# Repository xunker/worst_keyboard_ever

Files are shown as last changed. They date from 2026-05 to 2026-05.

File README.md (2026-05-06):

# Worst. Keyboard. Ever.

https://github.com/xunker/worst_keyboard_ever

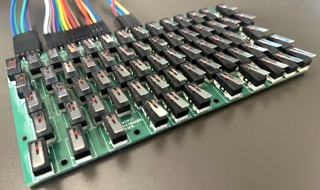
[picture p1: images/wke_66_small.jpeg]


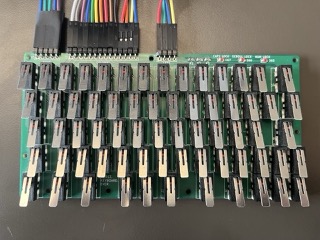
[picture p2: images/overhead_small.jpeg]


It's a mechanical keyboard made from limit switches[^1]. Sorry.

## Parts

Part                      | Quantity | Notes
--------------------------|----------|------
[PCB](kicad)              | 1        | Using more than one is not recommended
Omron D2F-FL              | 66       | [^2]
1N4148 Diode              | 66       | SOT-123 package recommended, but you can use LL34 (MiniMELF) if you like things that roll away while you're soldering them
2.54MM pin (male) headers | 23 pos   | Use whatever fits in the holes[^3]
0805 LED                  | 3        | Prefer the kind that light up; LEDs that don't light up are not good indicators
0805 330 ohm resistor     | 3        | You'll learn to solder SMD components and you'll _like it_

Your microcontroller is not listed. Use whatever you like. There's [QMK firmware](#firmware) for the Pi Pico if you want it.

## Matrix

| row/col | 0 | 1 | 2 | 3 | 4 | 5 | 6 | 7 | 8 | 9 | 10  | 11 | 12 | 13 |
|---|---|-----|-----|---|---|---|---|-----|-----|-----|-----|---|---|---|
| 0 | esc  | 1 | 2 | 3 | 4 | 5 | 6 | 7 | 8 | 9 | 0 | - | = | bksp  |
| 1 | tab  | q | w | e | r | t | y | u | i | o | p | [ | ] | \ |
| 2 | cap  | a | s | d | f | g | h | j | k | l | ; | ' | ent  | --- |
| 3 | shft | z | x | c | v | b | n | m | , | . | / | shft | up | fn |
| 4 | ctrl | win | alt |  --- | spc1 | spc2 | spc3 | --- | --- | alt | app | left | down | right |

## LEDs

The caps/num/scroll LEDs are _active-low_. That means the `common` pin should be connected to your microcontroller's VCC, and the LEDs are activated by pulling the approriate pin to ground.

If you're using a 3.3V MCU like the Pi Pico, do **NOT** connect `common` to a 5V source like VBUS or USB power. If you do that, you'll _fry_ your MCU you'll be sad.

## Firmware

There is QMK firmware available, targeting the Raspberry Pi Pico (RP2040). Find it in the [qmk_firmware](qmk_firmware/keyboards/wke_66) directory.

If you don't want to build it yourself, and you don't need to customize anything, a [prebuild .u2f file](./wke_wke_66_default.uf2) is also available.

# Useless Questions

## Why?

Because I needed **one** switch, but it was cheaper to buy a whole gross of them.

## The switches are too close together

I recommend installing smaller fingers on one or both hands.

## I've used worse keyboards than this!

1) "Worst. Keyboard. Ever." is a product/marketing name.
2) No you haven't.

## A Scroll Lock LED? Really?

Don't worry about it. No one in the history of the world has **ever** used Scroll Lock. No, not even _that one guy from the internet_, he's lying.

## Is there an ISO version?

Assuming drills exist, yes.

## It has no legends!

If you're asking for key legends, that means you want to use this as an _actual_ keyboard to type _real_ things. That's a crazy idea, you should stand up and slowly back away.

But, if you insist, [here are some suggestions](SERIOUSLY.md#no-legends).

## Your soldering is terrible!

Wrong, _MY_ soldering is AWESOME. My _cat's_ soldering is terrible.

Note: Cat hair seen in the [photos](images/) is __not included__.

# License

[CC BY-NC-SA 4.0](LICENSE)

[^1]: Variously called "limit switches", "lever switches", or "detect switches".

[^2]: Be honest, you're not going to use _real_ Omron switches, are you? You're going to use some knock-off, admit it.

[^3]: That's what she said.

I sure hope you enjoy soldering diodes!

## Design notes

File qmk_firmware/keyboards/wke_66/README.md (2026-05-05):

# Worst Keyboard Ever -- 66 key edition
## wke_66

Main project URL: https://github.com/xunker/worst_keyboard_ever

wke_66

* Keyboard Maintainer: [M Nielsen](https://github.com/xunker/worst_keyboard_ever)
* Hardware Supported: Pi Pico (RP2040)
* Hardware Availability: https://raspberrypi.org

## Building this firmware

(This assumes you've already cloned the QMK repo and configured your environment.)

First, clone the [parent repo](https://github.com/xunker/worst_keyboard_ever).

Then, symlink the `qmk_firmware/keyboards/wke_66` directory in to your main "qmk_firmware" directory:

```bash
ln -s qmk_firmware/keyboards/wke_66 ~/qmk_firmware/keyboards/wke_66
```

(You could also just copy the files to `~/qmk_firmware/keyboards/wke_66`, but where's the fun in that?)

> [!IMPORTANT]
>
> If you're using MacOS, you need to install a specific version of `gcc-arm-embedded`, the default version in Homebrew _is broken_.
>
> `brew install --cask gcc-arm-embedded`

Now, build the firmware:
```bash
# from ~/qmk_firmware
PATH=/Applications/ArmGNUToolchain/15.2.rel1/arm-none-eabi/bin:$PATH qmk compile -kb wke/wke_66 -km default

# you can also lint the firmware with `qmk lint -kb wke/wke_66 -km default`
```

This will make a `wke_wke_66_default.uf2`. Drag that file to your Pi Pico and you're off!

## Bootloader

To re-enter the Bootloader (like if you need to flash new firmware), you have 3 options:

* **Bootmagic reset**: Hold down the key at (0,0) in the matrix (usually the top left key or Escape) and plug in the keyboard
* **Physical button**: Hold down the "bootsel" button on the Pi Pico **while** plugging the board in to USB
* **Keycode**: While the keyboard is connected and running, hold down the `fn` key and press the "App"/"Menu" button

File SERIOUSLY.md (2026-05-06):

# Worst. Keyboard. Ever.

https://github.com/xunker/worst_keyboard_ever

# Serious answers

## Why?

These lever-style switches, even the cheap copies, have a really satisfying
action. So I found myself wondering what a keyboard made from these would feel
like.

I wanted to use larger SS-5GL/KW-11/KW-12 switches, but that made the board to
large and would cost too much to fab.

## Why is it "the worst"?

### No legends

There's no easy way to add legends.

Using masking tape or a label maker is the most obvious solution, but that's
more work than most people are prepared to do (after soldering 66 SMD diodes and
198 switch pins).

If I'd been more diligent in the PCB design, I would have made sure to have
silkscreens in the top-left corner of each unit, but I didn't know enough about
Kicad at the time (May 2022).

Here are some ideas for adding legends:
* Permanent Marker with an extra-fine tip, and a very steady hand
* Masking tape
* Label printer + scissors
* Laser marking
* 3D-printed or laser-cut "piano-key" cover

### Narrow key spacing

The key spacing is `2*(switch width)`, and that's too narrow for most people's
fingers.

I needed to keep the PCB under 100MM^2 in order to qualify for the cheap fab
options, and this was the best option.

### No "home row" bumps

Not that you'll be touch-typing on this, but even if you could there are no home
row bumps.

You could use a bit of glue to make a bump, I guess.

The best way would be to use D2F-L3/D2F-FL3 "simulated roller" switches in place
of "F" and "J", but I didn't think of that ahead of time.

### Fingers catch on levers

Your fingers will catch on the edge of the levers, and that really can't be
helped.

However, having the switches in the other orientation (levers pointing toward
the far-edge of the PCB) was **even worse**.

### Outboard MCU

When I make this PCB I had no idea what MCU I wanted to use. And even if I did,
that would have pushed the size past the $5 tier for PCB fabbing.

So I made the MCU connection completely outboard, via header connectors. It's
not a terrible thing to do, but I could have done better.

## Why it's not "the worst"

Despite the name, it does have some things going for it.

* It **is** a fully functional mechanical keyboard
* Small, very portable
* Fully compatible with QMK, ZMK, KMK, etc
* Great soldering practice

## Ideas for the future

### Use "simulated roller" switches

Use D2F-L3/D2F-FL3 "simulated roller" switches for "home row" bumps, and for
arrow keys. That would make it much easier to differntiate those keys.

### Align silkscreen legends better

Make sure the PCB legend silkscreens are aligned in the top-left corner, so they
are visible even when the switch is soldered in place.

### More switch placement options

Have more options for spacebar and arrow key locations.

Add options for ISO pipe and enter.

Add options for JIS pipe and backspace.

### RGB

Why not? To paraphrase Bill Hicks, "you're already within the Dark Lord's
domain."

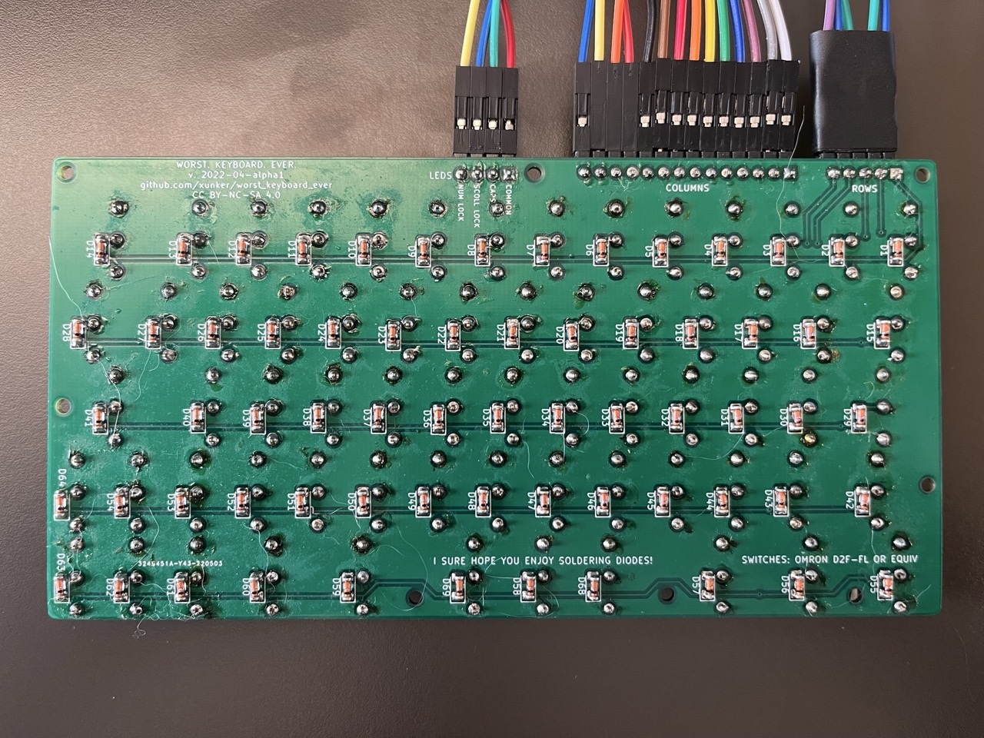
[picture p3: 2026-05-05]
images/underneath.jpeg

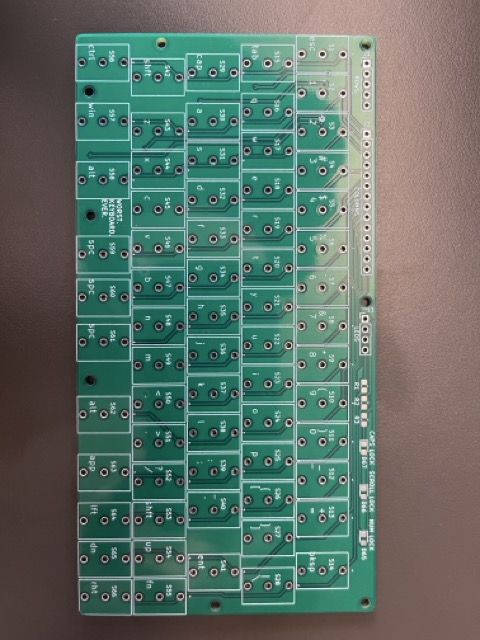
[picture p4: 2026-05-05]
images/pcb_front.jpeg

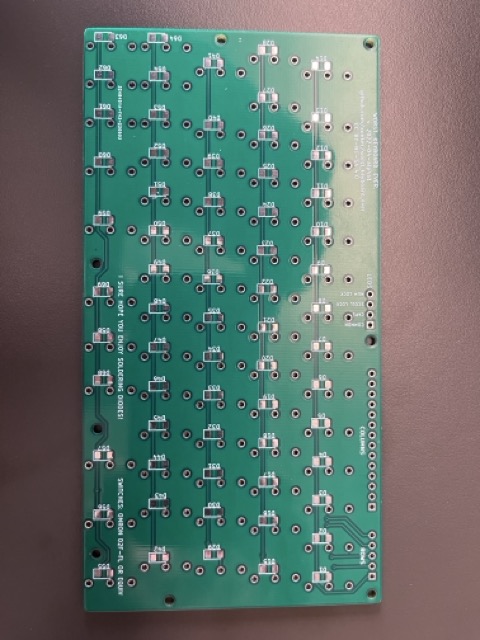
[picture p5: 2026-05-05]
images/pcb_not_front.jpeg

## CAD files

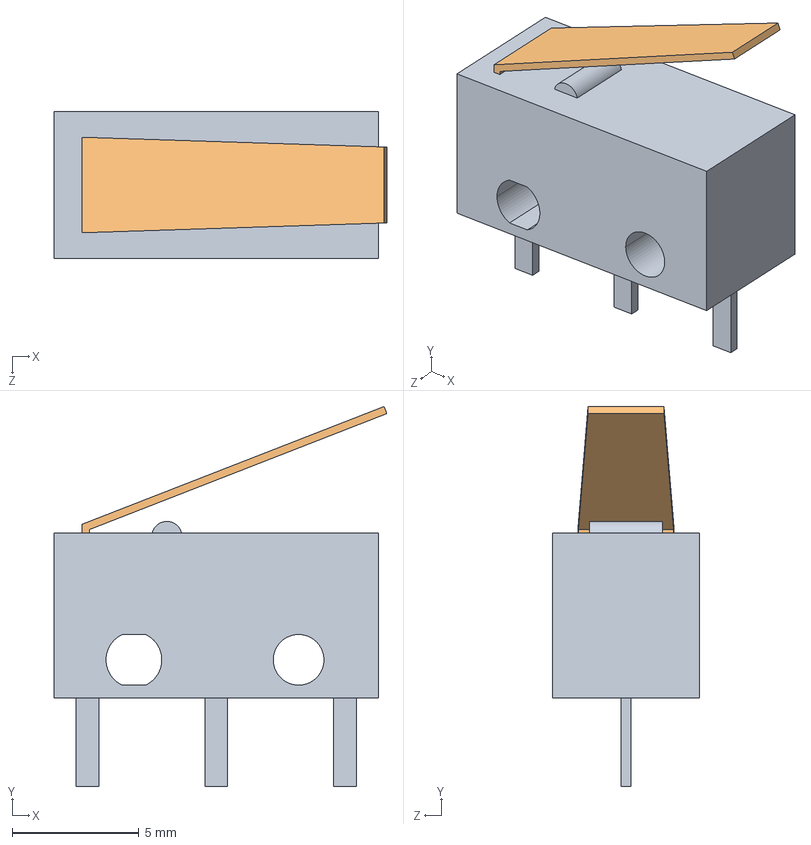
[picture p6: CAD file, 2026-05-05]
kicad/D2F-FL/D2F-FL.step
13.1 x 15.0 x 5.80 mm
D2F_FL_BASE
D2F_FL_ACTUATOR

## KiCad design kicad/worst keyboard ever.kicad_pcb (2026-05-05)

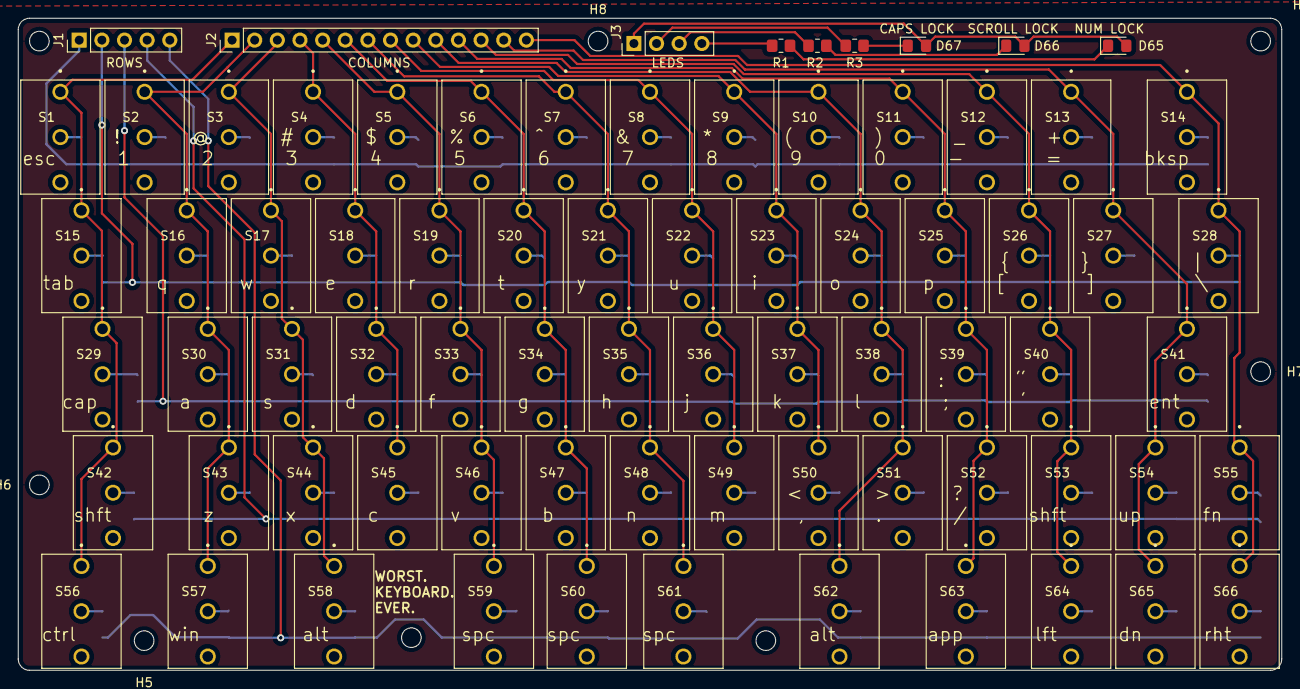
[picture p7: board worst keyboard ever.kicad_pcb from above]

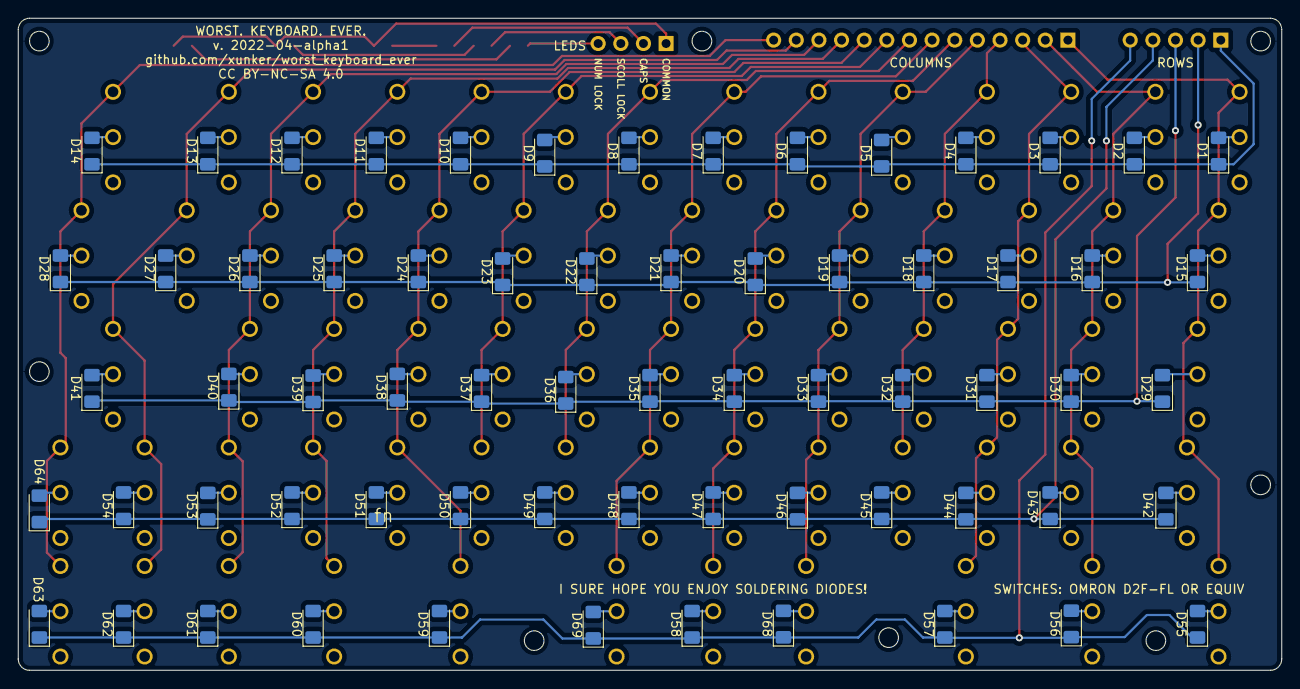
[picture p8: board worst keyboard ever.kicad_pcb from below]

Board: 2 copper layers, 141.8 x 73.1 mm, 149 parts (66 on the bottom side), 92 nets.

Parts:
D1, D2, D3, D4, D5, D6, D7, D8, D9, D10, D11, D12, D13, D14, D15, D16, D17, D18, D19, D20, D21, D22, D23, D24, D25, D26, D27, D28, D29, D30, D31, D32, D33, D34, D35, D36, D37, D38, D39, D40, D41, D42, D43, D44, D45, D46, D47, D48, D49, D50, D51, D52, D53, D54, D55, D56, D57, D58, D59, D60, D61, D62, D63, D64, D68, D69: D; D_1206_3216Metric_Pad1.42x1.75mm_HandSolder
D65, D66, D67: LED; LED_0805_2012Metric_Pad1.15x1.40mm_HandSolder
H1, H2, H3, H4, H5, H6, H7, H8: MountingHole; MountingHole_2.2mm_M2_DIN965
J1: Conn_01x05_Male; PinHeader_1x05_P2.54mm_Vertical
J2: Conn_01x14_Male; PinHeader_1x14_P2.54mm_Vertical
J3: Conn_01x04_Male; PinHeader_1x04_P2.54mm_Vertical
R1, R2, R3: R; R_0805_2012Metric_Pad1.20x1.40mm_HandSolder
S1, S2, S3, S4, S5, S6, S7, S8, S9, S10, S11, S12, S13, S14, S15, S16, S17, S18, S19, S20, S21, S22, S23, S24, S25, S26, S27, S28, S29, S30, S31, S32, S33, S34, S35, S36, S37, S38, S39, S40, S41, S42, S43, S44, S45, S46, S47, S48, S49, S50, S51, S52, S53, S54, S55, S56, S57, S58, S59, S60, S61, S62, S63, S64, S65, S66: D2F-FL; SW_D2F-FL_rotated_1.5xwide

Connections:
/CAPS_LOCK_LED: J3.2, R3.2
/LED_COMMON: D65.2 (A), D66.2 (A), D67.2 (A), J3.1
/NUM_LOCK_LED: J3.4, R1.2
/Row1: D1.1 (K), D2.1 (K), D3.1 (K), D4.1 (K), D5.1 (K), D6.1 (K), D7.1 (K), D8.1 (K), D9.1 (K), D10.1 (K), D11.1 (K), D12.1 (K), D13.1 (K), D14.1 (K), J1.1
/Row2: D15.1 (K), D16.1 (K), D17.1 (K), D18.1 (K), D19.1 (K), D20.1 (K), D21.1 (K), D22.1 (K), D23.1 (K), D24.1 (K), D25.1 (K), D26.1 (K), D27.1 (K), D28.1 (K), J1.2
/Row3: D29.1 (K), D30.1 (K), D31.1 (K), D32.1 (K), D33.1 (K), D34.1 (K), D35.1 (K), D36.1 (K), D37.1 (K), D38.1 (K), D39.1 (K), D40.1 (K), D41.1 (K), J1.3
/Row4: D42.1 (K), D43.1 (K), D44.1 (K), D45.1 (K), D46.1 (K), D47.1 (K), D48.1 (K), D49.1 (K), D50.1 (K), D51.1 (K), D52.1 (K), D53.1 (K), D54.1 (K), D64.1 (K), J1.4
/Row5: D55.1 (K), D56.1 (K), D57.1 (K), D58.1 (K), D59.1 (K), D60.1 (K), D61.1 (K), D62.1 (K), D63.1 (K), D68.1 (K), D69.1 (K), J1.5
/SCROLL_LOCK_LED: J3.3, R2.2
Col1: J2.1, S1.COM, S15.COM, S29.COM, S42.COM, S56.COM
Col2: J2.2, S2.COM, S16.COM, S30.COM, S43.COM, S57.COM
Col3: J2.3, S3.COM, S17.COM, S31.COM, S44.COM, S58.COM
Col4: J2.4, S4.COM, S18.COM, S32.COM, S45.COM
Col5: J2.5, S5.COM, S19.COM, S33.COM, S46.COM, S59.COM
Col6: J2.6, S6.COM, S20.COM, S34.COM, S47.COM, S60.COM
Col7: J2.7, S7.COM, S21.COM, S35.COM, S48.COM, S61.COM
Col8: J2.8, S8.COM, S22.COM, S36.COM, S49.COM
Col9: J2.9, S9.COM, S23.COM, S37.COM, S50.COM
Col10: J2.10, S10.COM, S24.COM, S38.COM, S51.COM, S62.COM
Col11: J2.11, S11.COM, S25.COM, S39.COM, S52.COM, S63.COM
Col12: J2.12, S12.COM, S26.COM, S40.COM, S53.COM, S64.COM
Col13: J2.13, S13.COM, S27.COM, S41.COM, S54.COM, S65.COM
Col14: J2.14, S14.COM, S28.COM, S55.COM, S66.COM
unnamed: D1.2 (A), S1.NO
unnamed: D2.2 (A), S2.NO
unnamed: D3.2 (A), S3.NO
unnamed: D4.2 (A), S4.NO
unnamed: D5.2 (A), S5.NO
unnamed: D6.2 (A), S6.NO
unnamed: D7.2 (A), S7.NO
unnamed: D8.2 (A), S8.NO
unnamed: D9.2 (A), S9.NO
unnamed: D10.2 (A), S10.NO
unnamed: D11.2 (A), S11.NO
unnamed: D12.2 (A), S12.NO
unnamed: D13.2 (A), S13.NO
unnamed: D14.2 (A), S14.NO
unnamed: D15.2 (A), S15.NO
unnamed: D16.2 (A), S16.NO
unnamed: D17.2 (A), S17.NO
unnamed: D18.2 (A), S18.NO
unnamed: D19.2 (A), S19.NO
unnamed: D20.2 (A), S20.NO
unnamed: D21.2 (A), S21.NO
unnamed: D22.2 (A), S22.NO
unnamed: D23.2 (A), S23.NO
unnamed: D24.2 (A), S24.NO
unnamed: D25.2 (A), S25.NO
unnamed: D26.2 (A), S26.NO
unnamed: D27.2 (A), S27.NO
unnamed: D28.2 (A), S28.NO
unnamed: D29.2 (A), S29.NO
unnamed: D30.2 (A), S30.NO
unnamed: D31.2 (A), S31.NO
unnamed: D32.2 (A), S32.NO
unnamed: D33.2 (A), S33.NO
unnamed: D34.2 (A), S34.NO
unnamed: D35.2 (A), S35.NO
unnamed: D36.2 (A), S36.NO
unnamed: D37.2 (A), S37.NO
unnamed: D38.2 (A), S38.NO
unnamed: D39.2 (A), S39.NO
unnamed: D40.2 (A), S40.NO
unnamed: D41.2 (A), S41.NO
unnamed: D42.2 (A), S42.NO
unnamed: D43.2 (A), S43.NO
unnamed: D44.2 (A), S44.NO
unnamed: D45.2 (A), S45.NO
unnamed: D46.2 (A), S46.NO
unnamed: D47.2 (A), S47.NO
unnamed: D48.2 (A), S48.NO
unnamed: D49.2 (A), S49.NO
unnamed: D50.2 (A), S50.NO
unnamed: D51.2 (A), S51.NO
unnamed: D52.2 (A), S52.NO
unnamed: D53.2 (A), S53.NO
unnamed: D54.2 (A), S54.NO
unnamed: D55.2 (A), S56.NO
unnamed: D56.2 (A), S57.NO
unnamed: D57.2 (A), S58.NO
unnamed: D58.2 (A), S60.NO
unnamed: D59.2 (A), S62.NO
unnamed: D60.2 (A), S63.NO
unnamed: D61.2 (A), S64.NO
unnamed: D62.2 (A), S65.NO
unnamed: D63.2 (A), S66.NO
unnamed: D64.2 (A), S55.NO
unnamed: D65.1 (K), R1.1
unnamed: D66.1 (K), R2.1
unnamed: D67.1 (K), R3.1
unnamed: D68.2 (A), S59.NO
unnamed: D69.2 (A), S61.NO

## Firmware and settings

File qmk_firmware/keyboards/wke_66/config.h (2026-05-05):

// based on of https://github.com/numToStr/qmk_firmware/blob/picopad/keyboards/picopad/config.h
// SPDX-License-Identifier: GPL-2.0-or-later

#pragma once

/*
 * Feature disable options
 *  These options are also useful to firmware size reduction.
 */

/* disable debug print */
//#define NO_DEBUG

/* disable print */
//#define NO_PRINT

/* disable action features */
//#define NO_ACTION_LAYER
//#define NO_ACTION_TAPPING
//#define NO_ACTION_ONESHOT

#define RP2040_BOOTLOADER_DOUBLE_TAP_RESET // Activates the double-tap behavior
#define RP2040_BOOTLOADER_DOUBLE_TAP_RESET_TIMEOUT 200U // Timeout window in ms in which the double tap can occur.
#define RP2040_BOOTLOADER_DOUBLE_TAP_RESET_LED GP25 // Specify a optional status led by GPIO number which blinks when entering the bootloader

// #define WS2812_PIO_USE_PIO1 // Force the usage of PIO1 peripheral, by default the WS2812 implementation uses the PIO0 peripheral

/*
 * LED Indicators
 * https://docs.qmk.fm/features/led_indicators
 */
#define LED_CAPS_LOCK_PIN	GP22   // Pin 29
#define LED_SCROLL_LOCK_PIN GP26 // Pin 31, ADC0
#define LED_NUM_LOCK_PIN GP27    // Pin 32, ADC1
#define LED_PIN_ON_STATE 0       // LEDs on PCB are active-low

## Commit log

2026-05-05 initial commit, only took 4 years
    [D2F-FL.step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]
2026-05-06 drill > scissors
2026-05-06 Add LED info and voltage warning
